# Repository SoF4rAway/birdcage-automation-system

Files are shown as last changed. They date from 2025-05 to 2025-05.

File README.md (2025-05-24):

# Automated Birdcage Management System

This project implements an automated system for managing pet birdcages, focusing on automating feeding, water refill, and cage cleaning using ultrasonic sensors, water level sensors, and microcontrollers. The system also integrates with Arduino IoT Cloud for remote monitoring and notifications, providing a hands-free experience for bird owners, especially during long absences.

## Table of Contents
- [Installation](#installation)
- [Usage](#usage)
- [Features](#features)
- [Configuration](#configuration)
- [System Architecture](#system-architecture)
- [Contributing](#contributing)
- [License](#license)
- [Contact](#contact)

## Installation

Follow these steps to install and run the project:

### Prerequisites
- Arduino IDE
- Arduino Uno R4 WiFI
- Arduino IoT Cloud Maker License
- HC-SR04 Ultrasonic sensor
- Water level sensor
- Servo motor
- IoT-enabled device for integration with Arduino IoT Cloud

### Setup

1. **Clone the repository**:
    ```bash
    git clone https://github.com/sof4raway/automated-birdcage-system.git
    cd automated-birdcage-system
    ```

2. **Install Arduino Libraries**:
   Ensure the following libraries are installed in your Arduino IDE:
   - `ArduinoIoTCloud`
   - `ArduinoCloudThing`
   - `NewPing`
   - `uRTCLib`
   - `DHT Sensor Library`
   - `AccelStepper`

3. **Upload the Code to Arduino**:
   Connect your Arduino board and upload the provided `.ino` file using the Arduino IDE.

4. **Wiring**:
   Follow the schematic in the documentation to connect the sensors and actuators to the microcontroller.

5. **Set up Arduino IoT Cloud**:
   - Configure your Arduino IoT Cloud dashboard with the appropriate variables to monitor sensor data.
   - Connect your Arduino board to WiFi and link it to the IoT Cloud for remote monitoring.

## Usage

Once the code is uploaded and the wiring is complete:

1. **Automatic Feeding and Watering**: The system automatically monitors and refills the bird's food and water using the connected sensors.
2. **Cage Cleaning**: The automatic scrubbing system is activated according to a schedule, ensuring the cage remains clean with minimal residue.
3. **Remote Monitoring**: Use the Arduino IoT Cloud dashboard or mobile app to monitor the bird's conditions, including food and water levels, and receive notifications.

## Features
- Automated Feeder Refill System: Monitors and refills the food with a tolerance of ±1.0 cm
- Atutomated Water Refill System: Monitors and refills the water with a tolerance of ±0.5 cm
- Automated Bird Dropping Cleaning: Scrubs and Spray Water to reduce manual maintenance
- Disinfectant Sprayer: periodic disinfection
- Remote Monitoring: Arduino IoT Cloud integration for real-time updates and notifications.

## Configuration
Make sure to configure the environment variables for WiFi and IoT Cloud settings in your Arduino code:

```bash
const char SSID[] = "your_wifi_ssid";
const char PASS[] = "your_wifi_password";
```
For Arduino IoT Cloud integration, use the appropriate cloud dashboard and ensure your device is registered and linked to the correct variables.

## System Architecture
The project structure is as follows:
``` bash
project-root/
├── src/
│   ├── capstone-ta_may09a.ino          # Main Arduino code
│   ├── thingProperties.h # Arduino IoT Cloud Properties
│   ├── ArduinoSecrets.h # Configuration etc.
└── README.md
```

## Citation
If you find this work useful for your research, please consider citing the following paper:

- **Author** : Muhammad Farid Rahman, and Rifki Suwandi
- **Title** : Rancang Bangun Sistem Otomatisasi Sangkar Burung Berbasis Mikrokontroler
- **Type** : Theses
- **Publisher** : Andalas University
- **Year** : 2024

Here are some BibTex Formate on APA, IEEE, and Harvard Style :
#### APA Style
```bibtex
@thesis{Rahman2024,
  author    = {Muhammad Farid Rahman and Rifki Suwandi},
  title     = {Rancang Bangun Sistem Otomatisasi Sangkar Burung Berbasis Mikrokontroler},
  year      = {2024},
  school    = {Andalas University},
  type      = {Thesis}
}
```

#### IEEE Style
```bibtex
@thesis{Rahman2024,
  author    = {M. F. Rahman and R. Suwandi},
  title     = {Rancang Bangun Sistem Otomatisasi Sangkar Burung Berbasis Mikrokontroler},
  year      = {2024},
  school    = {Andalas University},
  type      = {Thesis}
}
```
#### Harvard Style
```bibtex
@thesis{Rahman2024,
  author    = {Rahman, M. F. and Suwandi, R.},
  title     = {Rancang Bangun Sistem Otomatisasi Sangkar Burung Berbasis Mikrokontroler},
  year      = {2024},
  school    = {Andalas University},
  type      = {Thesis}
}
```

## Contact 
For any questions or feedback, feel free to reach out:
- **Name** : Muhammad Farid Rahman
- **Email** : muhammadfaridrahman.mfr@gmail.com
- **GitHub** : sof4raway

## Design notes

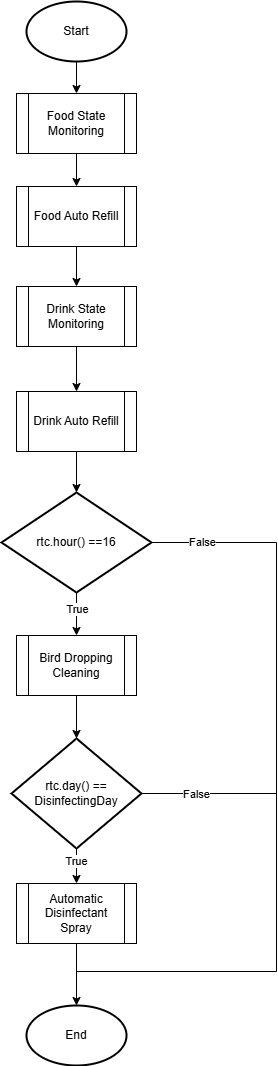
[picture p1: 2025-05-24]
system-flowchart.png

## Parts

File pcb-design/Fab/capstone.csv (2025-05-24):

Id | Designator | Footprint | Quantity | Designation | Supplier and ref
1 | R3,R4 | R_0805_2012Metric_Pad1.20x1.40mm_HandSolder | 2 | 10k
2 | J2,J3 | JST_PH_S2B-PH-K_1x02_P2.00mm_Horizontal | 2 | Conn_01x02_Pin
3 | J11 | CUI_PJ-002A | 1 | Barrel_Jack_Switch
4 | W_LV_SENSOR | JST_PH_S4B-PH-K_1x04_P2.00mm_Horizontal | 1 | Grove_Conn
5 | H2,H5,H1,H3 | MountingHole_2.2mm_M2_DIN965_Pad | 4 | MountingHole_Pad
6 | C5,C4,C3 | CP_Radial_D6.3mm_P2.50mm | 3 | 100u
7 | STP_MTR,ULT_SENSOR | JST_PH_S4B-PH-K_1x04_P2.00mm_Horizontal | 2 | Conn_01x04_Pin
8 | Q2,Q1 | TO-220-3_Vertical | 2 | TIP120
9 | A1 | Arduino_Uno_R4_WiFi_Shield | 1 | Arduino_Uno_R4_WiFi_Shield
10 | D2,D1 | D_DO-41_SOD81_P10.16mm_Horizontal | 2 | 1N4001
11 | R2,R1 | R_0805_2012Metric_Pad1.20x1.40mm_HandSolder | 2 | 1k
12 | U2,U1 | YAAJ_DCDC_StepDown_LM2596 | 2 | LM2596_DCDC
13 | DHT-11,WTR_PMP,SERVO_PWM | JST_PH_S3B-PH-K_1x03_P2.00mm_Horizontal | 3 | Conn_01x03_Pin
14 | J10 | PinSocket_1x04_P2.54mm_Horizontal | 1 | Conn_01x04_Socket
15 | A2 | Pololu_Breakout-16_15.2x20.3mm | 1 | A4988_DRV

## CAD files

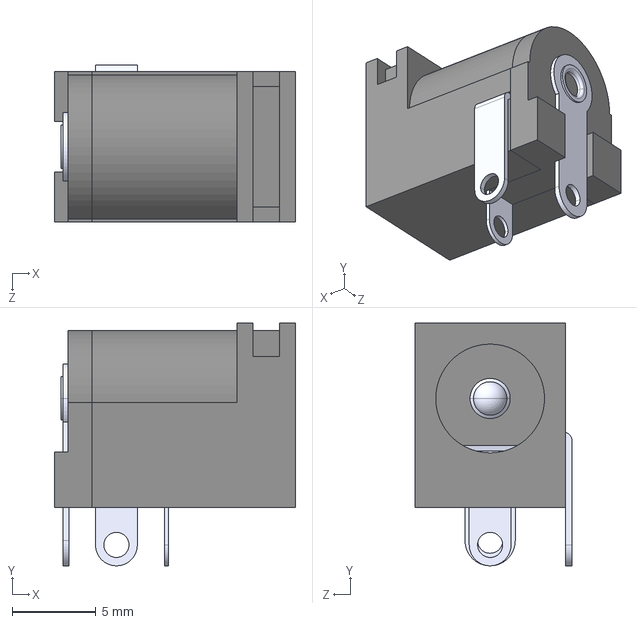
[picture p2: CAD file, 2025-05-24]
pcb-design/components/Barrel Jack/PJ-002A.step
14.4 x 14.5 x 9.40 mm

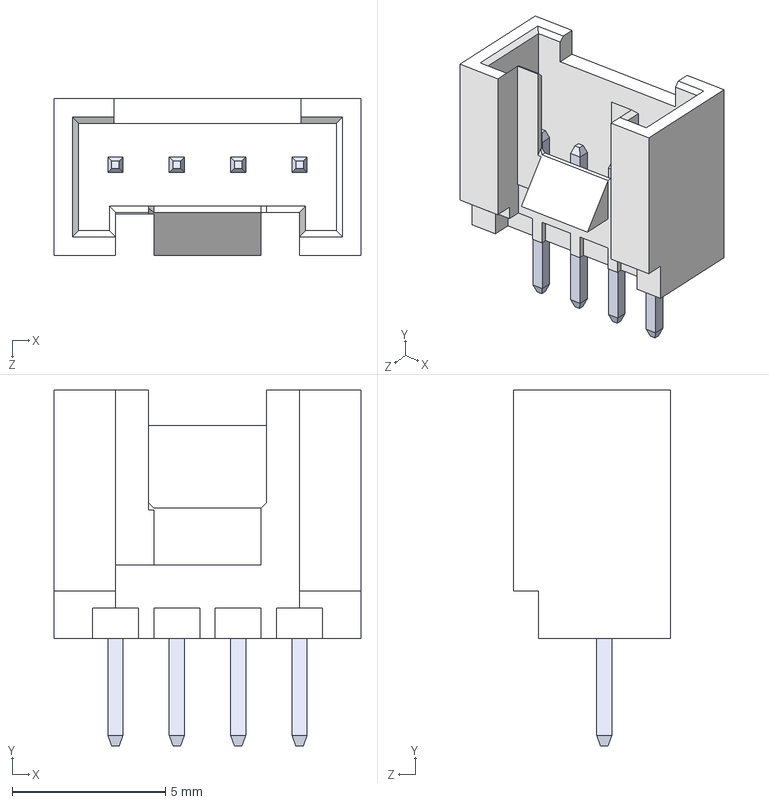
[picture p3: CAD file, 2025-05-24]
pcb-design/components/Grove Conn/110990030.step
10.0 x 11.6 x 5.10 mm

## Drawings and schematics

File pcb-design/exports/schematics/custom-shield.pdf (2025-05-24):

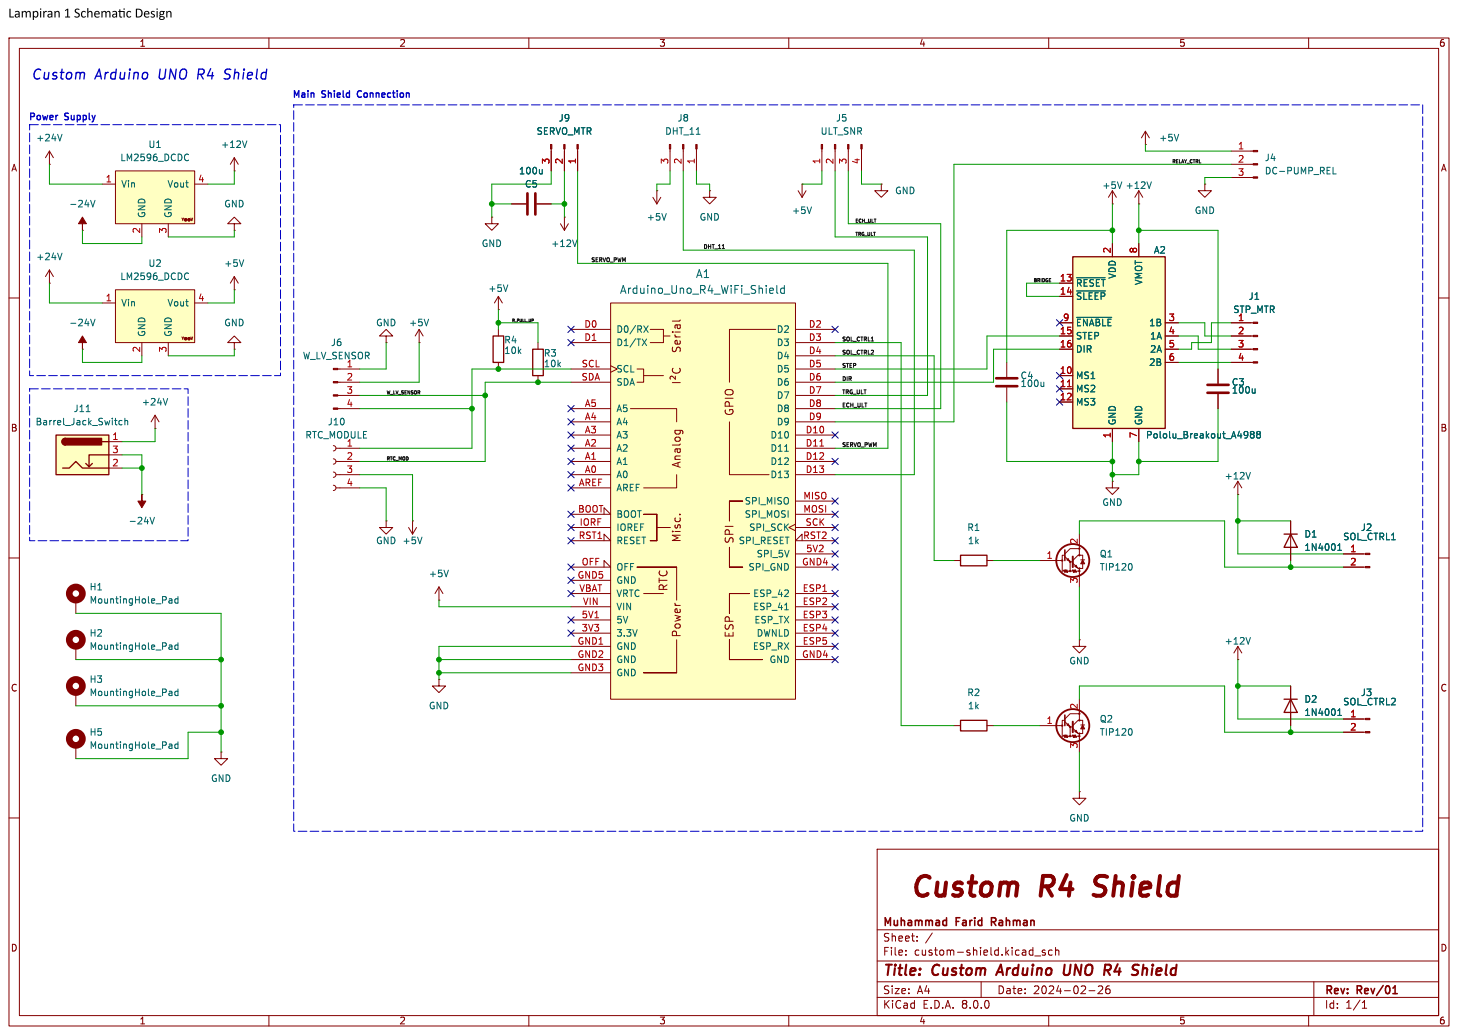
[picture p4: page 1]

Custom Arduino UNO R4 Shield

1 MS1 10 MS2 11 MS3 12 ~{RESET} 13 ~{SLEEP} 14 STEP 15 DIR 16 VDD

Id: 1/1 Title: Custom Arduino UNO R4 Shield

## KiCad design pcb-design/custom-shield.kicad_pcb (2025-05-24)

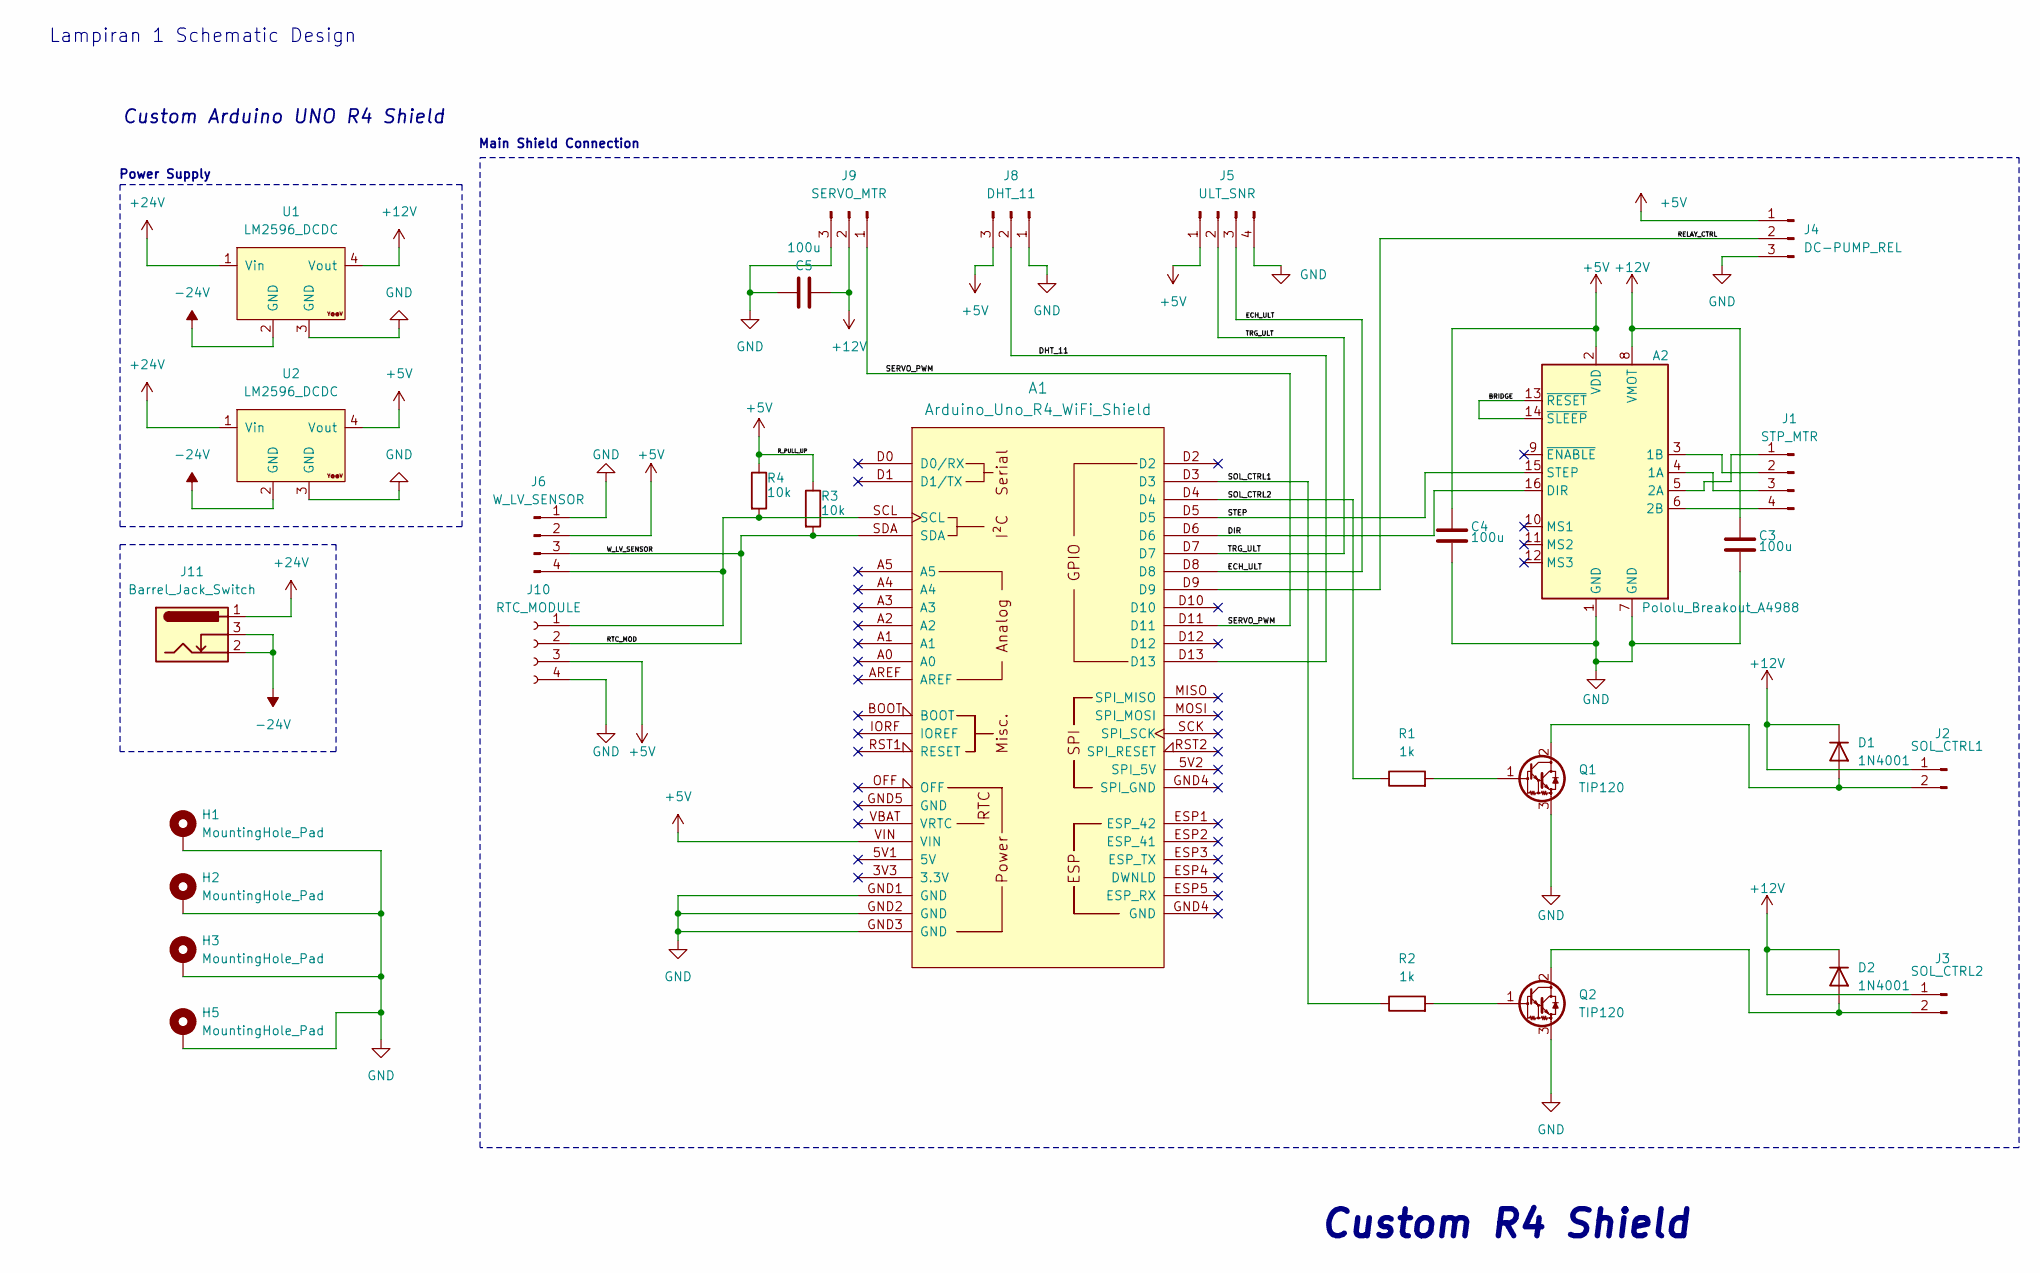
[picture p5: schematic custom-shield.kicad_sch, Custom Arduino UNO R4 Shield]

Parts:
A1: Arduino_Uno_R4_WiFi_Shield
A2: Pololu_Breakout_A4988; Pololu_Breakout-16_15.2x20.3mm
C3, C4, C5: 100u; CP_EIA-6032-28_Kemet-C_Pad2.25x2.35mm_HandSolder
D1, D2: 1N4001; D_DO-41_SOD81_P10.16mm_Horizontal
H1, H2, H3, H5: MountingHole_Pad; MountingHole_2.2mm_M2_DIN965_Pad
J1: STP_MTR; JST_PH_S4B-PH-K_1x04_P2.00mm_Horizontal
J2: SOL_CTRL1; JST_PH_S2B-PH-K_1x02_P2.00mm_Horizontal
J3: SOL_CTRL2; JST_PH_S2B-PH-K_1x02_P2.00mm_Horizontal
J4: DC-PUMP_REL; JST_PH_S3B-PH-K_1x03_P2.00mm_Horizontal
J5: ULT_SNR; JST_PH_S4B-PH-K_1x04_P2.00mm_Horizontal
J6: W_LV_SENSOR; JST_PH_S4B-PH-K_1x04_P2.00mm_Horizontal
J8: DHT_11; JST_PH_S3B-PH-K_1x03_P2.00mm_Horizontal
J9: SERVO_MTR; JST_PH_S3B-PH-K_1x03_P2.00mm_Horizontal
J10: RTC_MODULE; PinSocket_1x04_P2.54mm_Horizontal
J11: Barrel_Jack_Switch; CUI_PJ-002A
Q1, Q2: TIP120; TO-220-3_Vertical
R1, R2: 1k; R_0805_2012Metric_Pad1.20x1.40mm_HandSolder
R3, R4: 10k; R_0805_2012Metric_Pad1.20x1.40mm_HandSolder
U1, U2: LM2596_DCDC; YAAJ_DCDC_StepDown_LM2596

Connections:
+5V: A1.VIN, A2.2 (VDD), C4.1, J4.1, J5.1, J6.2, J8.3, J10.3, R3.1, R4.1, U2.4 (Vout)
+12V: A2.8 (VMOT), C3.1, C5.1, D1.1 (K), D2.1 (K), J2.1, J3.1, J9.2, U1.4 (Vout)
+24V: J11.1, U1.1 (Vin), U2.1 (Vin)
-24V: J11.2, J11.3, U1.2 (GND), U2.2 (GND)
/BRIDGE: A2.13 (~RESET), A2.14 (~SLEEP)
/DHT_11: A1.D13, J8.2
/DIR: A1.D6, A2.16 (DIR)
/ECH_ULT: A1.D8, J5.3
/RELAY_CTRL: A1.D9, J4.2
/RTC_MOD: A1.SDA, J6.3, J10.2, R3.2
/SERVO_PWM: A1.D11, J9.1
/SOL_CTRL1: A1.D3, R2.1
/SOL_CTRL2: A1.D4, R1.1
/STEP: A1.D5, A2.15 (STEP)
/TRG_ULT: A1.D7, J5.2
GND: A1.GND1 (GND), A1.GND2 (GND), A1.GND3 (GND), A2.1 (GND), A2.7 (GND), C3.2, C4.2, C5.2, H1.1, H2.1, H3.1, H5.1, J4.3, J5.4, J6.1, J8.1, J9.3, J10.4, Q1.3 (E), Q2.3 (E), U1.3 (GND), U2.3 (GND)
unnamed: A2.4 (1A), J1.3
unnamed: A2.3 (1B), J1.2
unnamed: A2.5 (2A), J1.1
unnamed: A2.6 (2B), J1.4
unnamed: D1.2 (A), J2.2, Q1.2 (C)
unnamed: D2.2 (A), J3.2, Q2.2 (C)
unnamed: A1.SCL, J6.4, J10.1, R4.2
unnamed: Q1.1 (B), R1.2
unnamed: Q2.1 (B), R2.2

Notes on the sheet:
Custom Arduino UNO R4 Shield
Power Supply
Main Shield Connection
Custom R4 Shield
Lampiran 1 Schematic Design

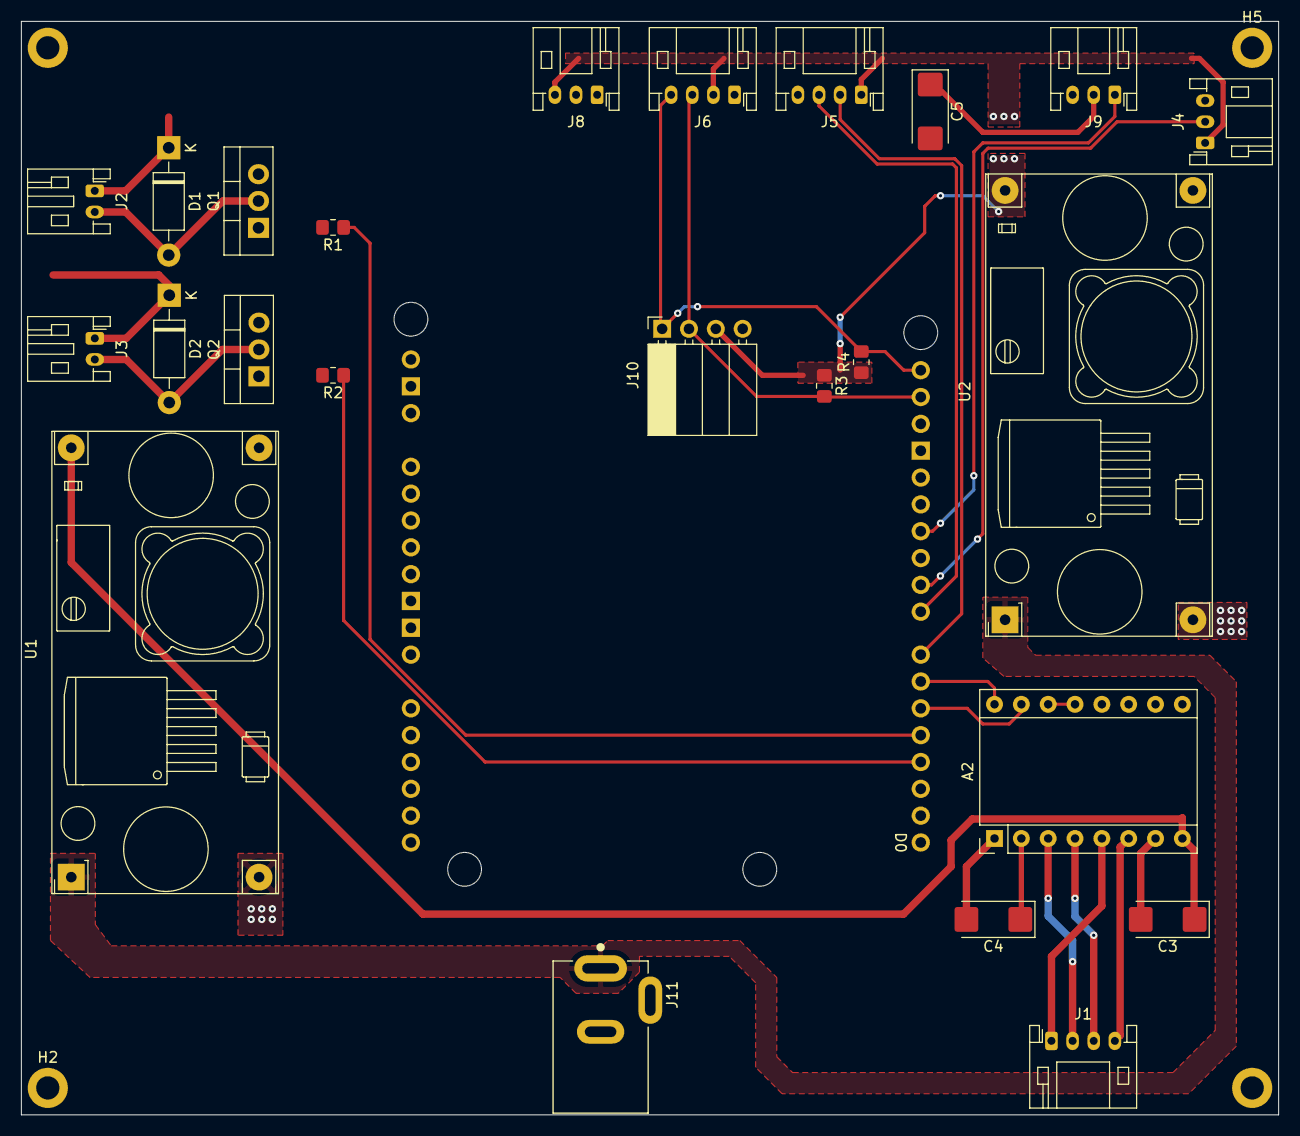
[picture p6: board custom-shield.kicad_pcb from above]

Board: 2 copper layers, 119.0 x 103.5 mm, 29 parts (0 on the bottom side), 25 nets.
